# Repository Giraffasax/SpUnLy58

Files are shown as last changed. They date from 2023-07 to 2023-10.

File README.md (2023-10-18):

# The SpUnLy58 Keyboard
The SpUnLy58 is **Sp**layed **Un**ibody Li**ly58** layout [6*4 + 4key] keyboard. This is a minimal design keyboard that is wireless first. This design requires a Nice!Nano v2, supports a Nice!View,there are no LEDs, and a case is recommended to protect the up to 750mAh battery.

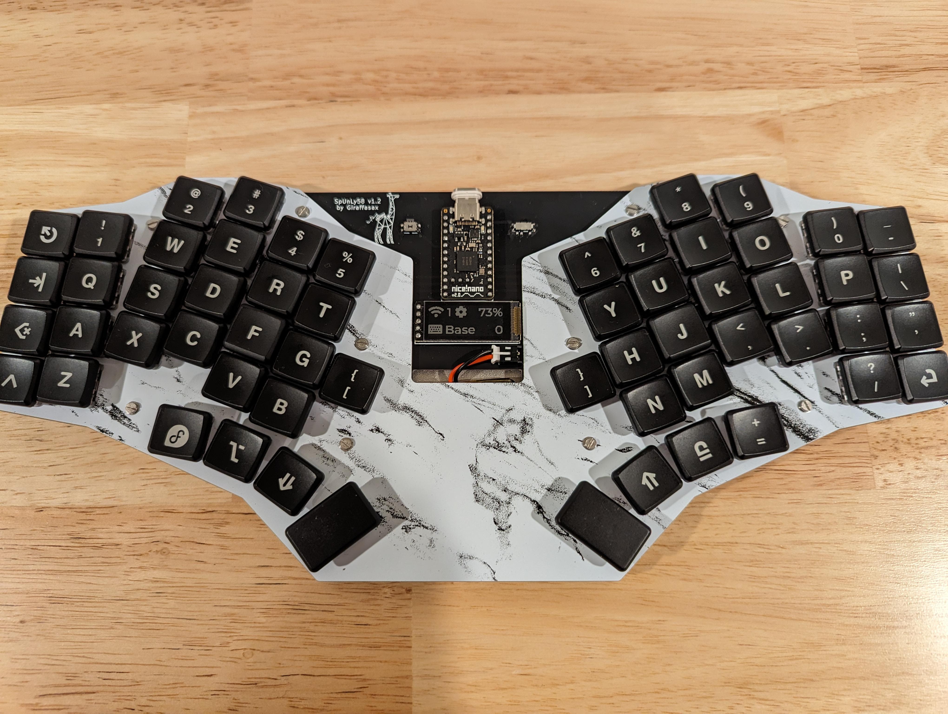
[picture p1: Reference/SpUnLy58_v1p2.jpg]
SpUnLy58_v1

<p style="text-align: center;">Build of SpUnLy v1.2 <p>

## Notable Features
- Choc V1 support [Hotswap and Soldered]
- "Split" unibody design with 19 deg angle (measured at middle finger column)
- Column Stagger
- Aggressive Pinky splay with Minimal splay for all other columns
- Aggressive Pinky stagger
- Fanned Thumb Cluster
- Nice!Nano v2 **[ REQUIRED ]**
- Nice!View Support
- JST Battery Connector

## SpUnLy58 v1.1 Updates
- Reduced vertical spacing from 18mm -> 17mm
- Increased battery cutout from 36x52mm -> 37x57mm
- Fixed incorrect JST connector footprint
## SpUnLy58 v1.2 Updates
- Removed inner and outer column splay
- Increased pinky stagger
- Reduced thumb key spacing and increased fan angle
- Added Ground fill

### Sponsor:
PCBway sponsored the manufacturing of v1.2 main pcb and the stainless steel bottom plates. If you would like to see more pictures and read my review see them [here.](Reference/PCBWay_Review.md)
___
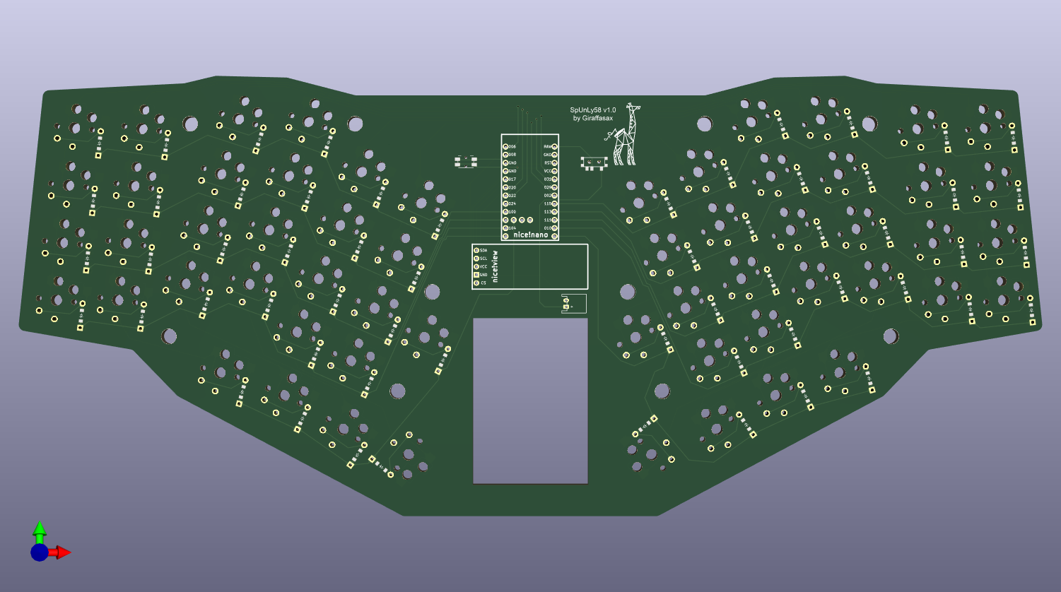
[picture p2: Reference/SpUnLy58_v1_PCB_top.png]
v1_PCB_top

<p style="text-align: center;">SpUnLy58 v1 PCB<p>

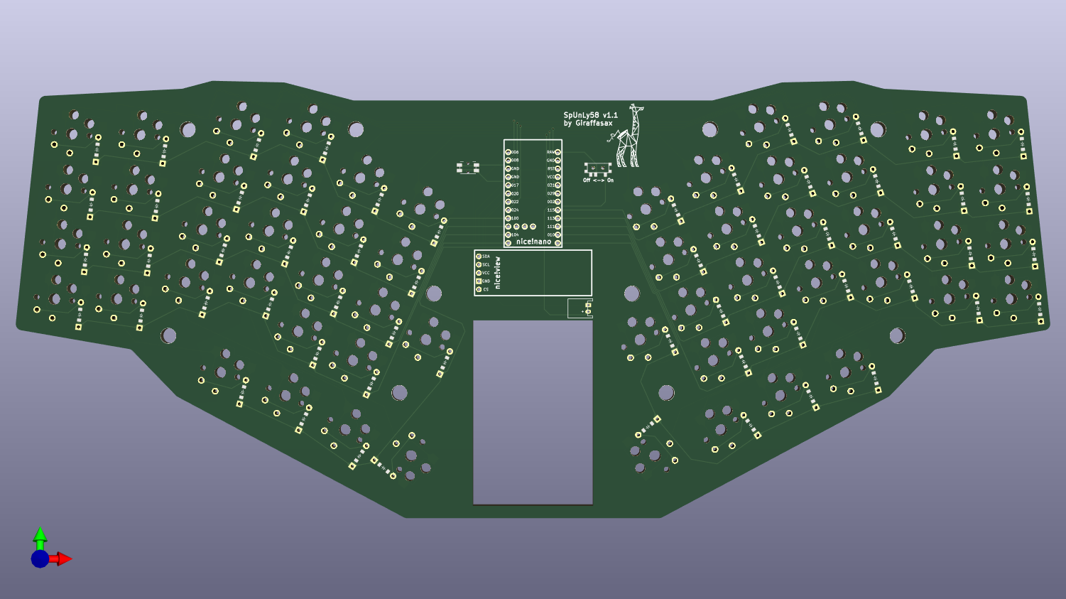
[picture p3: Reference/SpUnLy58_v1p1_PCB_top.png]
v1p1_PCB_top

<p style="text-align: center;">SpUnLy58 v1.1 PCB<p>

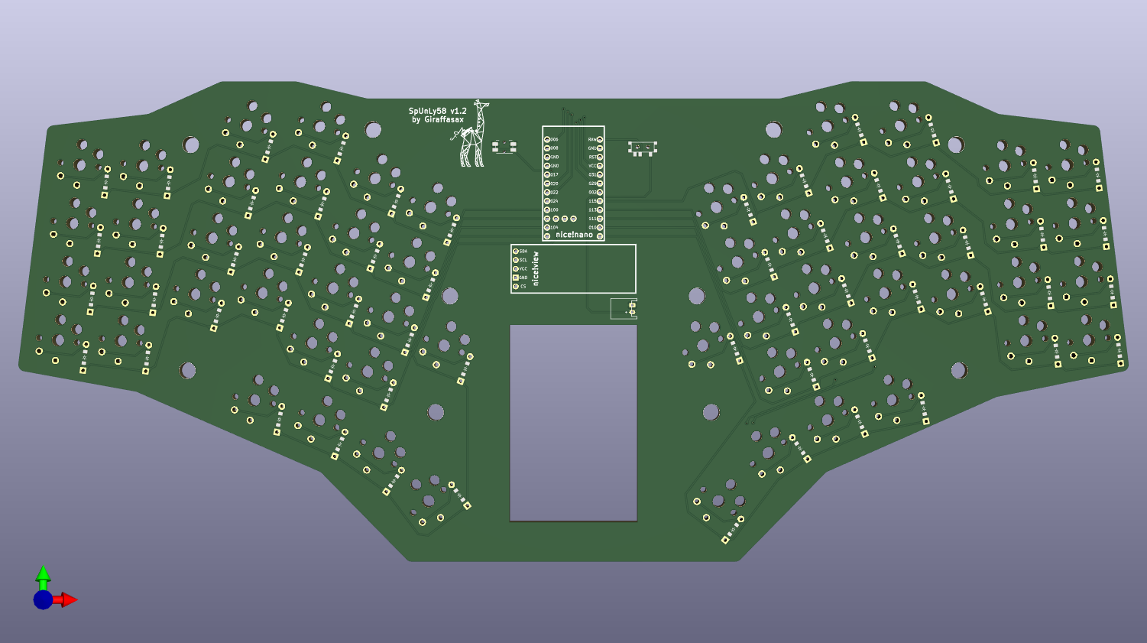
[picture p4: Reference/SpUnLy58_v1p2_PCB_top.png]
v1p2_PCB_top

<p style="text-align: center;">SpUnLy58 v1.2 PCB<p>

___
## Parts List 
| Name | Quantity | Example URL |
|---|---|---|
| SpUnLy58 PCB | 1  | https://github.com/Giraffasax/SpUnLy58/blob/main/KiCad/Gerber/SpUnLy58_Gerber.zip |
| Kailh Choc v1 Switches | 58 | https://typeractive.xyz/products/choc-switches?variant=46024772387047 |
| Kailh Choc v1 Keycaps (Choc Spacing) | 58 | https://fkcaps.com/custom/create/keycaps?option=mbk-pbt-pu&color=black |
| Nice!Nano v2 | 1 | https://typeractive.xyz/products/nice-nano |
| Nice!View or OLED (Optional) | 1 | https://typeractive.xyz/products/nice-view |
| Mill Max Ultra Low Profile Sockets (Optional) | 2 | https://www.littlekeyboards.com/collections/miscellaneous/products/ultra-low-profile-sockets |
| 1N4148W Diodes (SMD or TH) | 58 | https://typeractive.xyz/products/smd-diodes |
| Kailch Choc Hotswap Sockets (Optional) | 58 | https://typeractive.xyz/products/hotswap-sockets?variant=45742200324327 |
| Panasonic EVQPU Reset Switch | 1 | https://typeractive.xyz/products/reset-button |
| Alps miniature SPDT switch | 1 | https://typeractive.xyz/products/power-switch |
| JST PH 2.0mm Battery Jack | 1 | https://typeractive.xyz/products/battery-jack |
| 3.7v 750mAh 403450 Battery | 1 | https://typeractive.xyz/products/lithium-battery-750mah |

Note: I used the ultra low profile Mill Max sockets for both the controller and display to have them sit lower than the switch height to protect them in travel.

## Sandwich Case Part List
| Name | Quantity | Example URL |
|---|---|---|
| Bottom Plate - PCB | 0 or 1 | https://github.com/Giraffasax/SpUnLy58/blob/main/KiCad/Gerber/Bottom_Plate_Gerber.zip |
| Bottom Plate - Metal | 0 or 1 | https://github.com/Giraffasax/SpUnLy58/blob/main/KiCad/SpUnLy58_Bottom.step |
| Top Plate | 1 | https://github.com/Giraffasax/SpUnLy58/blob/main/KiCad/Gerber/Top_Plate_Gerber.zip |
| 6mm M2 Standoffs | 10 | https://splitkb.com/products/brass-m2-spacers?variant=42396969140483 |
| 4mm M2 Screws | 20 | https://splitkb.com/products/m2-screws?_pos=2&_sid=9c9502b8a&_ss=r |

## Firmware
ZMK Firmware: https://github.com/Giraffasax/zmk-SpUnLy58-config

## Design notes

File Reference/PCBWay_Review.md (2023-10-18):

# PCBWay Sponsored Review
## Background
After posting v1.0 of this project and it gaining some traction a PCBWay representative reached out to see if I would want them to sponsor my next iteration in exchange for a review. So I want to be up front that **I did receive a voucher for their services** which I used to help pay for the 5 main PCBs and 2 stainless steel bottom plates. I did not send this review to them beforehand. However, after posting the original review I was contacted and asked to remove the name of the competing China PCB manufacturer. To meet this request I have redacted the name and replaced it with "Unnamed PCB Supplier".

## Physical Comparison

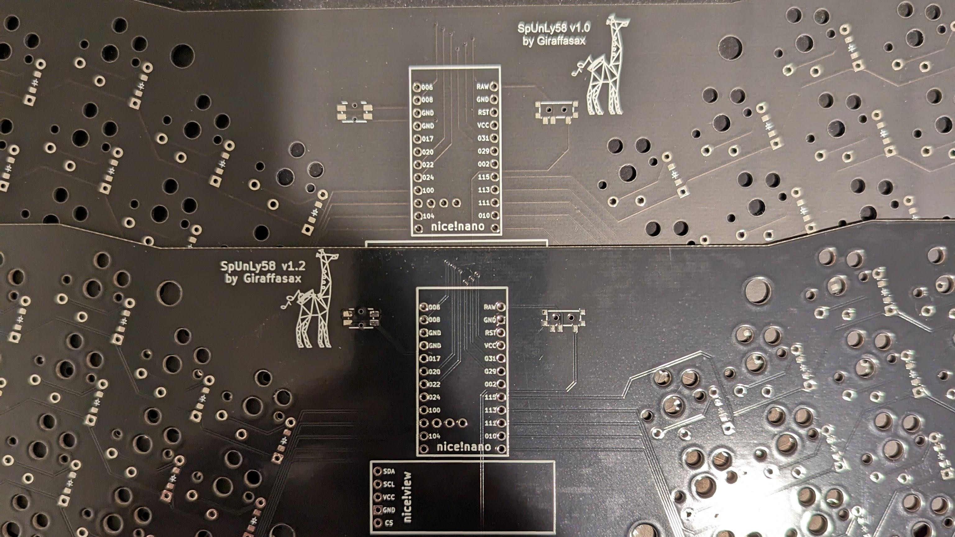
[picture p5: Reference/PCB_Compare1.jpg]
PCB Compare 1

<p style="text-align: center;">[top] "Unnamed PCB Supplier" Black [bottom] PCBWay Black</p>

First when comparing v1.0 that was printed by "Unnamed PCB Supplier" to v1.2 printed by PCBWay you can see that the "Unnamed PCB Supplier" "Black" PCB is a matte finish and a lighter tone while PCBWay's is a deeper black with a glossy finish. If you want a matte black from PCBWay there will be a slight up charge.

I was unable to directly compare the PCB weights as I added a ground fill on v1.2 that added quite a bit more material.

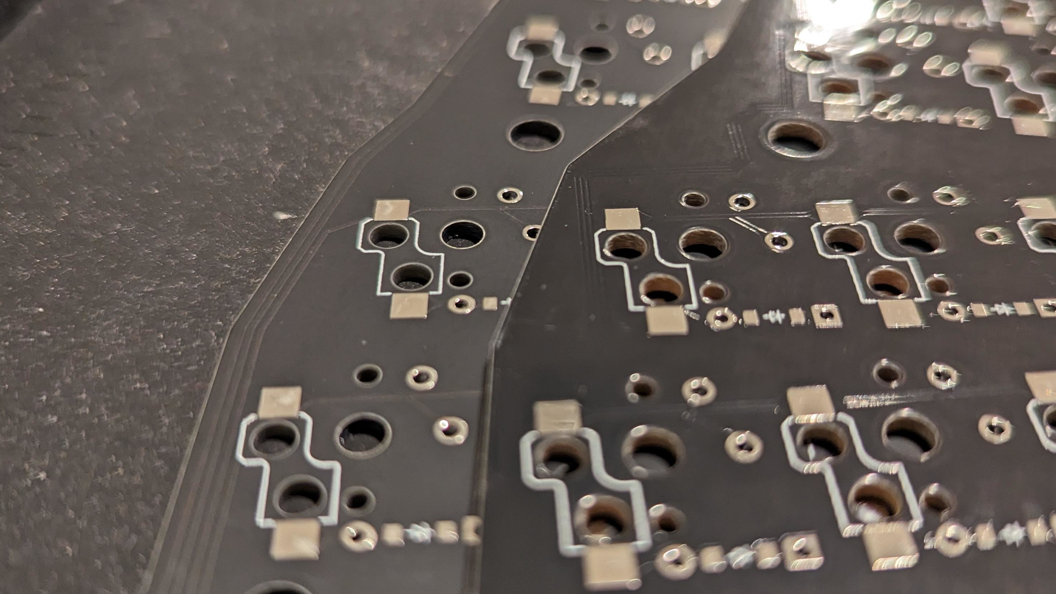
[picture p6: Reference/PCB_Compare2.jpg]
PCB Compare 1

<p style="text-align: center;">[left] "Unnamed PCB Supplier" Black [right] PCBWay Black</p>

Inspecting the pads and through holes on the PCBs I had a difficult time finding any differences on these very simple keyboard designs without any embedded controllers or other small components. The only difference I was able to see was a slight "wavy" appearance on the "Unnamed PCB Supplier" pads compared to the smoother appearance of the PCBWay. However I could not feel any variation in height of the "Unnamed PCB Supplier" pads and it did not affect my soldering whatsoever. So this is likely just cosmetic.

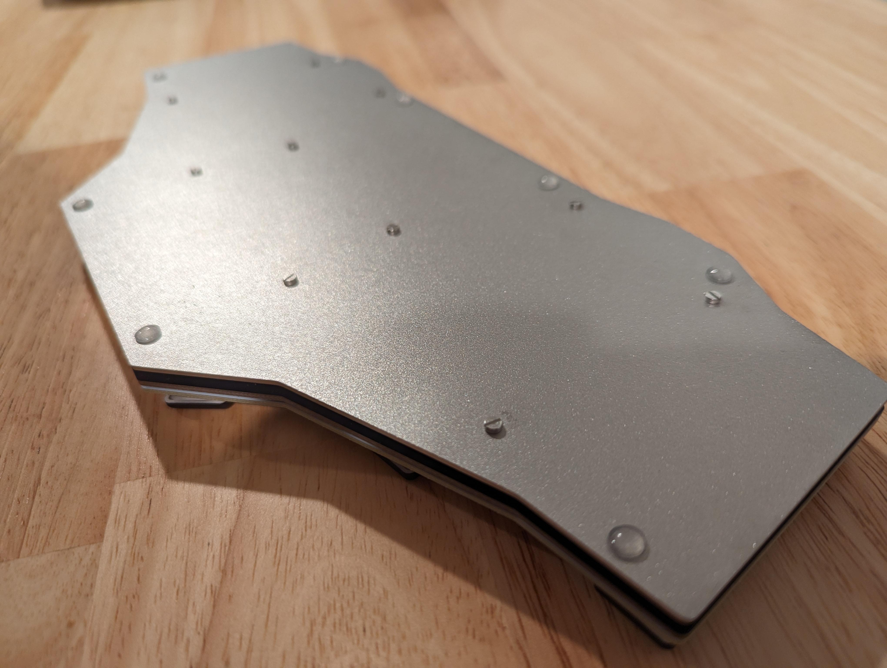
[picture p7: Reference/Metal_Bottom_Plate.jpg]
Metal_Bottom_Plate

<p style="text-align: center;">Stainless Steel Bottom Plate (PCBWay)</p>

I also put my PCBWay voucher towards getting a nice pair of stainless steel bottom plates for my work and home boards. I was able to upload a STEP file of the bottom plate to their "Sheet Metal" quote system. This service can be used for laser cutting and bending, but all I required was cutting. I selected a standard thickness of 1.5mm and chose a bead blasted finish which I think came out great.

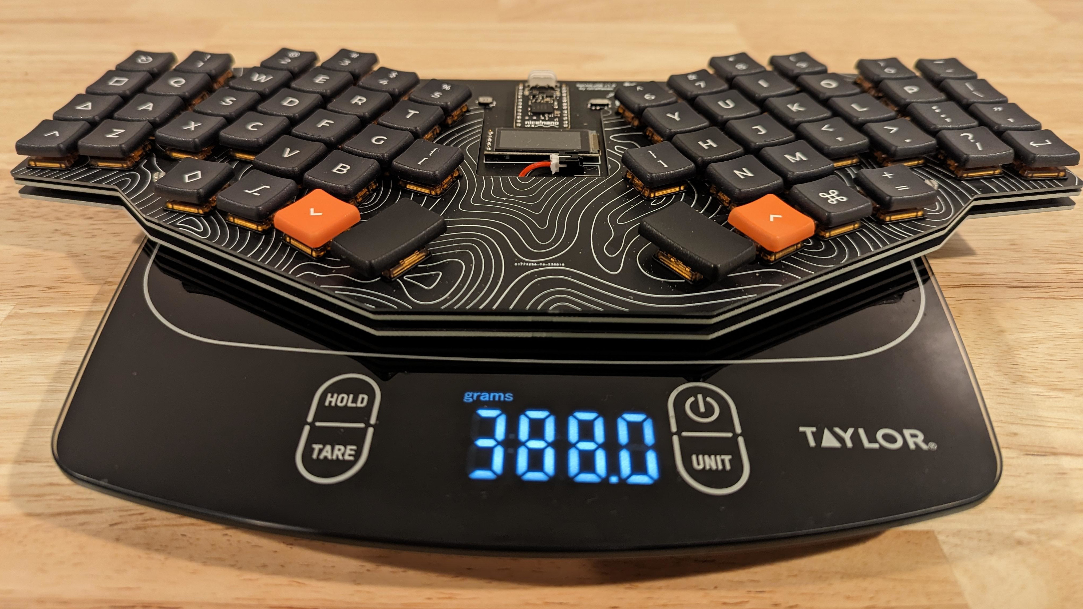
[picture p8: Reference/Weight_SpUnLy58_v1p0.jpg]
Weight_SpUnLy58_v1p0

<p style="text-align: center;">SpUnLy58 v1.0 assembled weight</p>

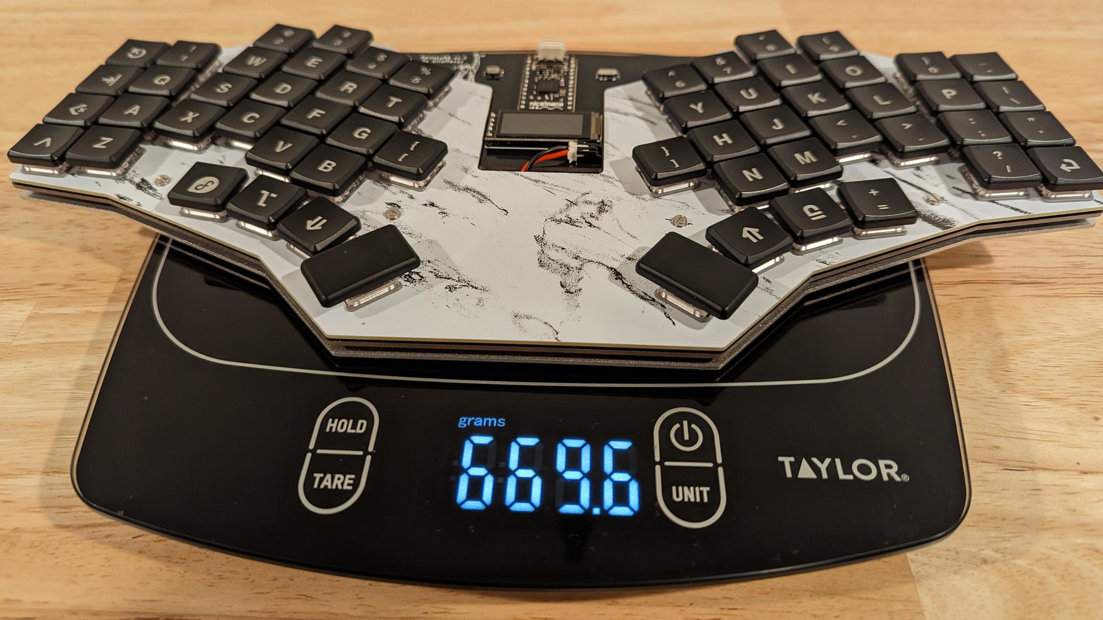
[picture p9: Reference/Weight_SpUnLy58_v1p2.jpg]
Weight_SpUnLy58_v1p2

<p style="text-align: center;">SpUnLy58 v1.2 assembled weight</p>

It also provides a pleasant heft. They have multiple options for each of the following materials: mild steel, stainless steel, aluminum, copper/brass, and acrylic. I think this service would also be a great option for switch plates or bent cases depending on your budget. "Unnamed PCB Supplier" and PCBWay also have 3d printing services that I have not tested.

## Purchase Experience
In both of my purchases with "Unnamed PCB Supplier" I submit my Gerber files, select my settings, and purchase. There seem to be some automated checks and they come back with pricing changes based on my PCBs. (ie. large number of cuts in the switch plate increasing the cost by $7.50)

When I did the same part submission process to PCBWay, I was asked some follow up questions by one of their engineers that helped me realize that I had accidentally uploaded the wrong gerber file. I was able to just email them the correct file, they updated my order, and I avoided a huge blunder. Now I cannot say whether or not they give this attention to all orders or just sponsored orders as this was my first purchase from them.

## Price Comparison (USD)
Now as this is a large unibody design with a number row [approx. 320x140mm] the prices are much higher compared to smaller DIY boards out there. Each value below is the cost of for a minimum order of 5 PCBs. Shipping was the cheapest available, typically DHL Express.

I chose the same settings for the PCBs. Black, 2-Layer, 1.6mm thick (1.2 for switch plate), HASL lead free.

| PCB Costs | Switch Plate | PCB | Bottom Plate | Shipping |
|---|---|---|---|---|
| "Unnamed PCB Supplier" v1.0 | $28.60 | $24.69 | $24.69 | $58.96 |
| "Unnamed PCB Supplier" v1.2 | $29.72 | N/A | $22.22 | $38.06 |
| PCBWay v1.2 | N/A | $94.80 | N/A | $30.56 |

Cost for two 1.5mm stainless steel bottom plates to be laser cut and bead blasted from PCBWay was **$80.12**

As you can see there was a reason why I didn't use PCBWay for all components of the build. Tinkering with the online quote system PCBWay can be 4-5x the cost of "Unnamed PCB Supplier" (before shipping). This isn't very noticeable on small boards where the difference is a few bucks. But when you scale it up to a board of my size the cost difference is sizable and it was cheaper to get 2 nice stainless steel bottom plates than have them cutout 5 plain FR4 plates.

## Conclusion
Overall PCBWay has slightly better cosmetic consistency with their pads, the customer service was great, and they have a lot of cool manufacturing options for metal and plastic materials. If you are looking to make a smaller board I recommend them, however for a large board like mine I cannot justify the price discrepancy without a sponsored voucher.

If you would like a more in depth review of PCBWay and other suppliers and their capabilities on a more complex PCB design, I recommend [Icamtuf's substack post.](https://lcamtuf.substack.com/p/comparing-hobby-pcb-vendors)

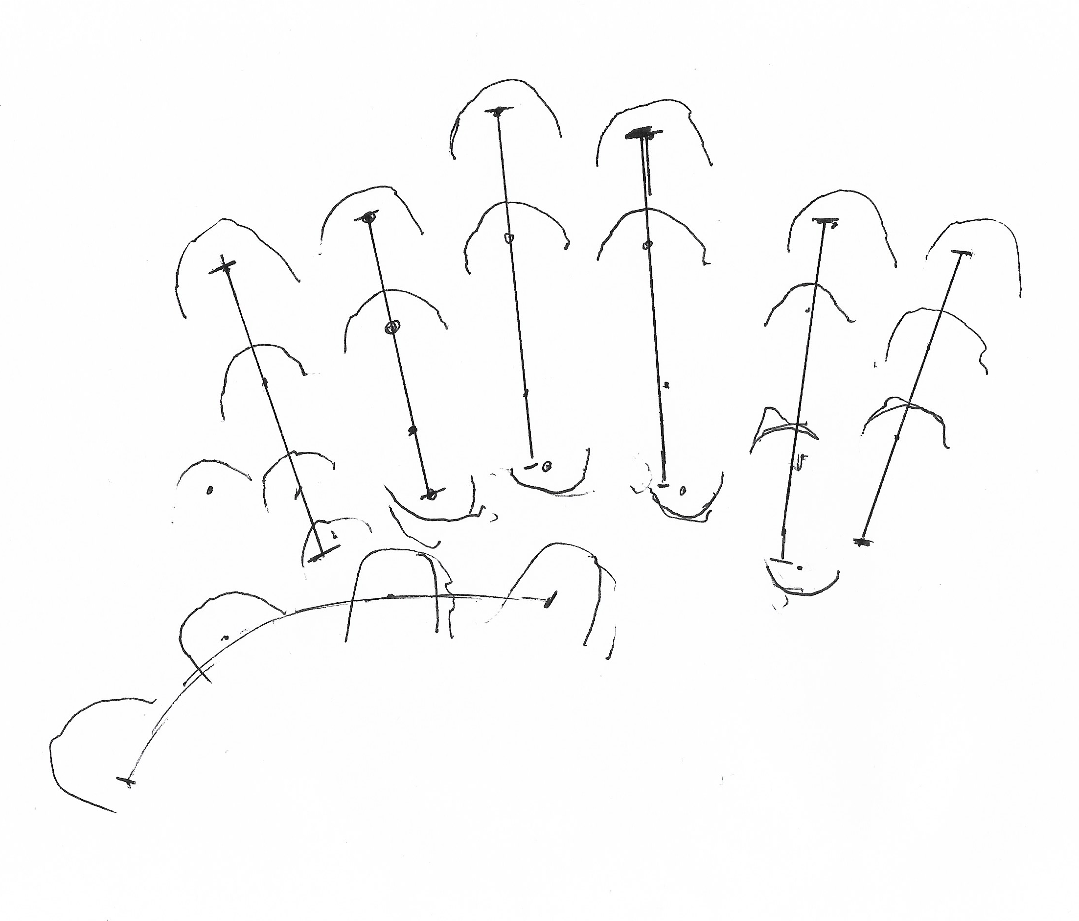
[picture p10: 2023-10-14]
Reference/Hand_Layout_Paper.png

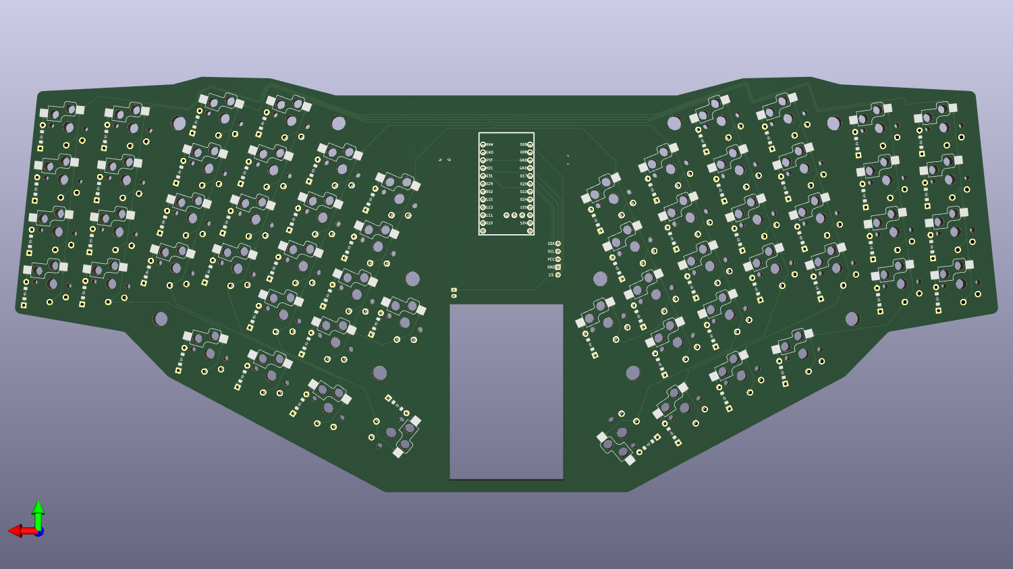
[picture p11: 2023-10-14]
Reference/SpUnLy58_v1p1_PCB_bottom.png

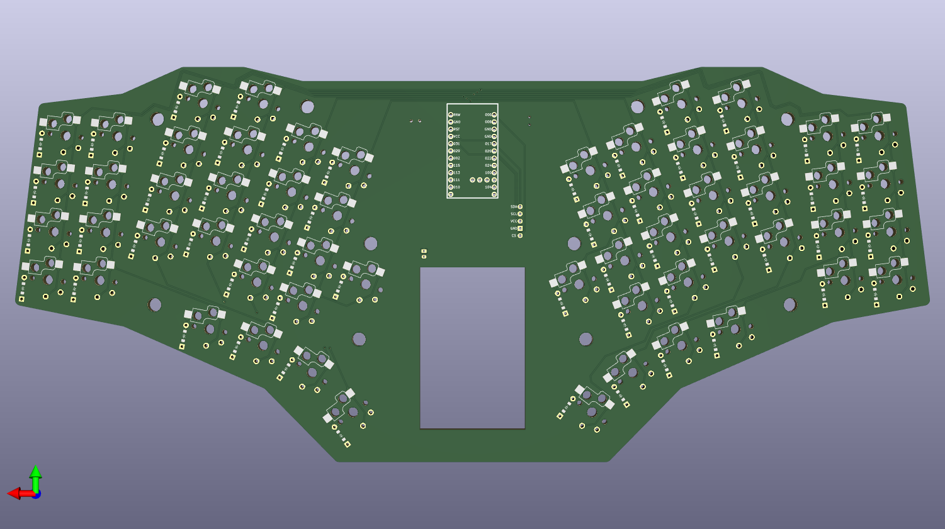
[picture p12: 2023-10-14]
Reference/SpUnLy58_v1p2_PCB_bottom.png

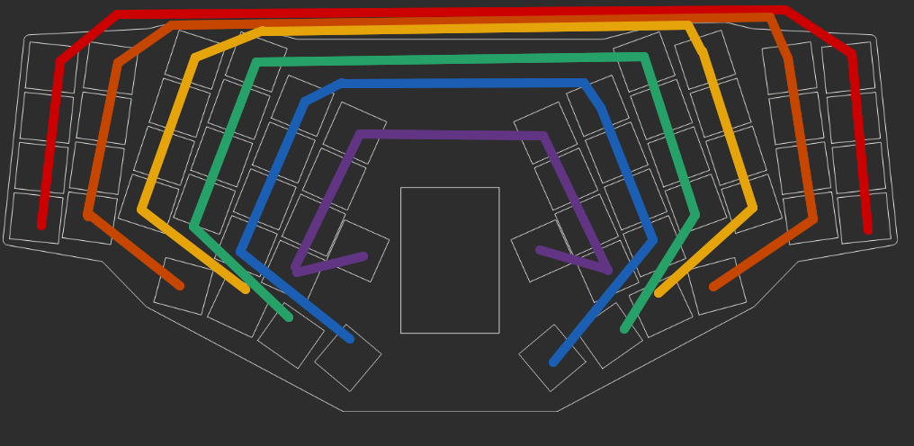
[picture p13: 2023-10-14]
Reference/Columns.png

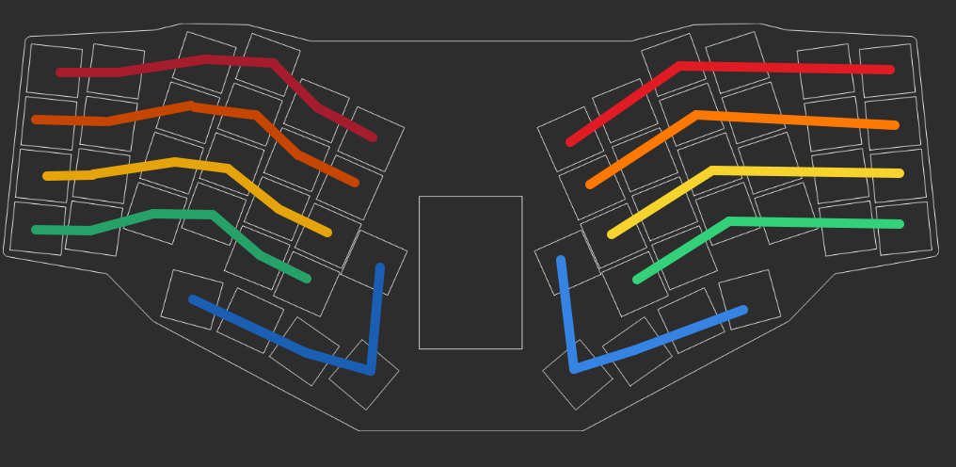
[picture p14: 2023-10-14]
Reference/Rows.png

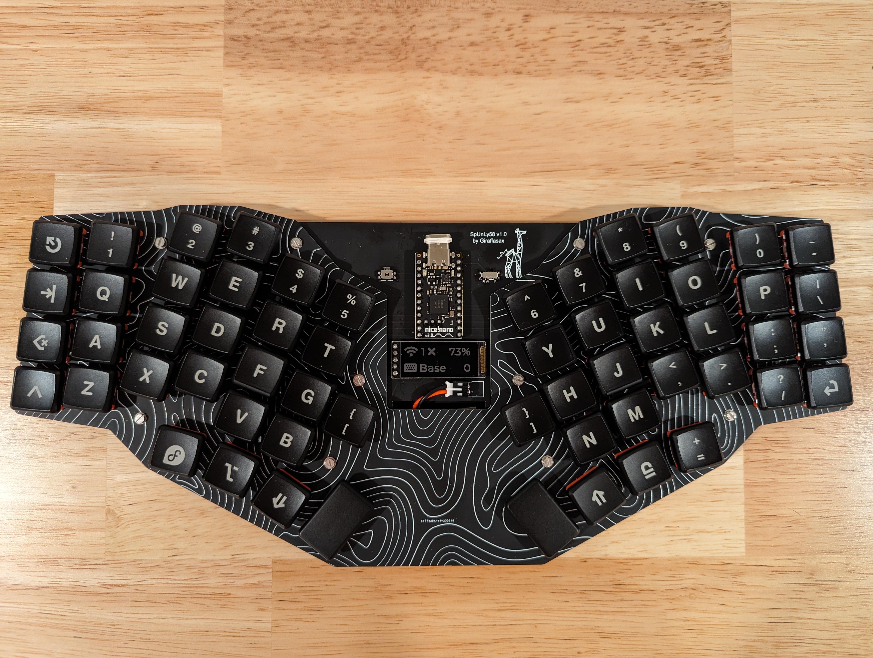
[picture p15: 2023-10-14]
Reference/SpUnLy58_v1.jpg

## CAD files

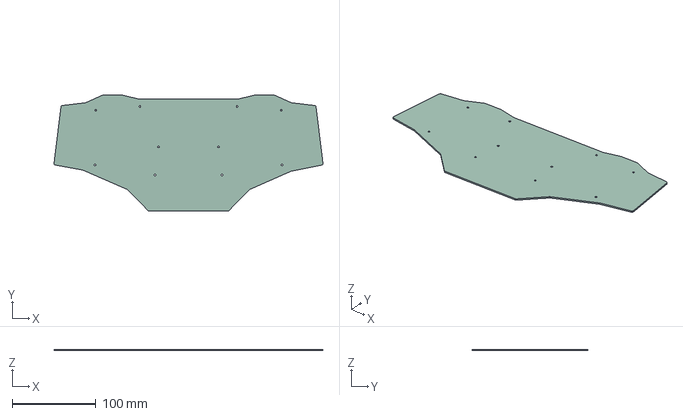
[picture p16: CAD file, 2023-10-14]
KiCad/SpUnLy58_Bottom.step
320.8 x 138.7 x 1.60 mm

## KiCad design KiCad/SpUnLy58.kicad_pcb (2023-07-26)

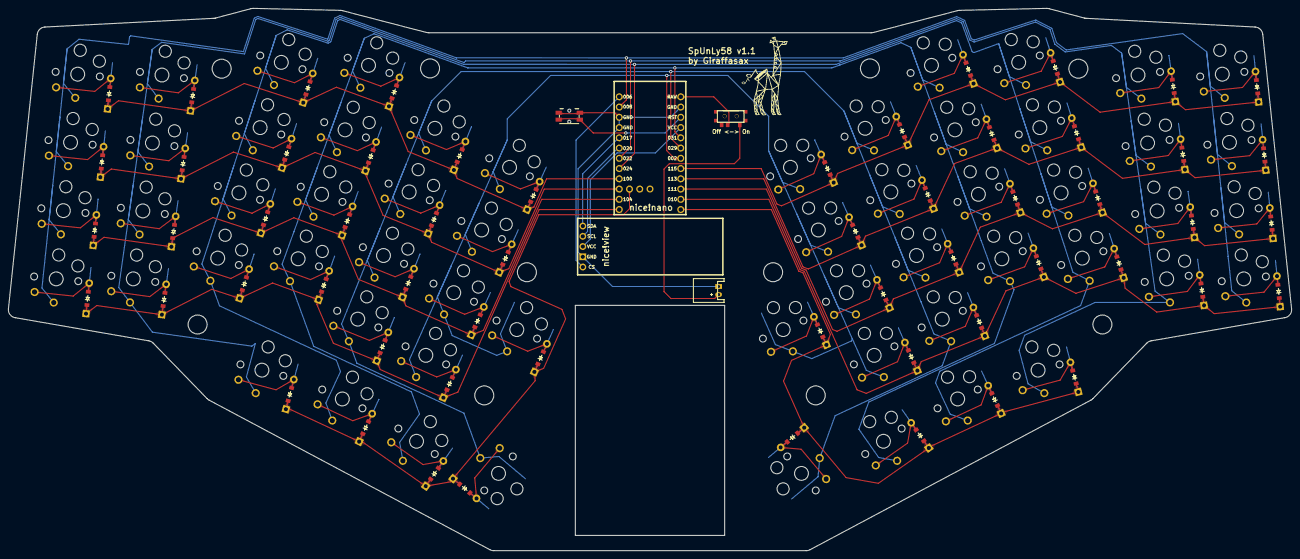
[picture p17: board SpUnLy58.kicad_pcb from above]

Board: 2 copper layers, 318.0 x 134.4 mm, 131 parts (0 on the bottom side), 82 nets.

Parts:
B1: Panasonic_EVQPUL_EVQPUC
D1, D2, D3, D4, D5, D6, D7, D8, D9, D10, D11, D12, D13, D14, D15, D16, D17, D18, D19, D20, D21, D22, D23, D24, D25, D26, D27, D28, D29, D30, D31, D32, D33, D34, D35, D36, D37, D38, D39, D40, D41, D42, D43, D44, D45, D46, D47, D48, D49, D50, D51, D52, D53, D54, D55, D56, D57, D58: ComboDiode
JST1: JST_PH_S2B-PH-K_02x2.00mm_Angled
MCU1: nice_nano
S1, S2, S3, S4, S5, S6, S7, S8, S9, S10, S11, S12, S13, S14, S15, S16, S17, S18, S19, S20, S21, S22, S23, S24, S25, S26, S27, S28, S29, S30, S31, S32, S33, S34, S35, S36, S37, S38, S39, S40, S41, S42, S43, S44, S45, S46, S47, S48, S49, S50, S51, S52, S53, S54, S55, S56, S57, S58: Kailh_socket_PG1350_optional_mkultra
T1: SPDT_C128955
_1, _2, _3, _4, _5, _6, _7, _8, _9, _10: HOLE_M2_TH
niceView1: niceView; niceView_headers

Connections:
GND: B1.1, JST1.1, MCU1.3, MCU1.4, MCU1.23, niceView1.2
P002: MCU1.18, S21.1, S22.1, S23.1, S24.1, S25.1, S50.1, S51.1, S52.1, S53.1, S54.1
P006: MCU1.1, niceView1.1
P008: MCU1.2, S1.1, S2.1, S3.1, S4.1, S30.1, S31.1, S32.1, S33.1
P009: D54.1, D55.1, D56.1, D57.1, D58.1, MCU1.13
P010: D30.1, D34.1, D38.1, D42.1, D46.1, D50.1, MCU1.14
P011: D3.1, D7.1, D11.1, D15.1, D19.1, D23.1, MCU1.10
P017: MCU1.5, niceView1.5
P020: MCU1.6, niceView1.4
P022: MCU1.7, S5.1, S6.1, S7.1, S8.1, S26.1, S34.1, S35.1, S36.1, S37.1, S55.1
P024: MCU1.8, S9.1, S10.1, S11.1, S12.1, S27.1, S38.1, S39.1, S40.1, S41.1, S56.1
P029: MCU1.19, S17.1, S18.1, S19.1, S20.1, S29.1, S46.1, S47.1, S48.1, S49.1, S58.1
P031: MCU1.20, S13.1, S14.1, S15.1, S16.1, S28.1, S42.1, S43.1, S44.1, S45.1, S57.1
P100: D4.1, D8.1, D12.1, D16.1, D20.1, D24.1, MCU1.9
P101: D25.1, D26.1, D27.1, D28.1, D29.1, MCU1.31
P104: D2.1, D6.1, D10.1, D14.1, D18.1, D22.1, MCU1.11
P106: D1.1, D5.1, D9.1, D13.1, D17.1, D21.1, MCU1.12
P111: D31.1, D35.1, D39.1, D43.1, D47.1, D51.1, MCU1.15
P113: D32.1, D36.1, D40.1, D44.1, D48.1, D52.1, MCU1.16
P115: D33.1, D37.1, D41.1, D45.1, D49.1, D53.1, MCU1.17
RAW: MCU1.24, T1.2
RST: B1.2, MCU1.22
VCC: MCU1.21, niceView1.3
center_home: D25.2, S25.2
index_bottom: D17.2, S17.2
index_home: D18.2, S18.2
index_num: D20.2, S20.2
index_top: D19.2, S19.2
inner_bottom: D21.2, S21.2
inner_home: D22.2, S22.2
inner_num: D24.2, S24.2
inner_top: D23.2, S23.2
layer_thumb: D28.2, S28.2
main_thumb: D29.2, S29.2
middle_bottom: D13.2, S13.2
middle_home: D14.2, S14.2
middle_num: D16.2, S16.2
middle_thumb: D27.2, S27.2
middle_top: D15.2, S15.2
mirror_center_home: D54.2, S54.2
mirror_index_bottom: D46.2, S46.2
mirror_index_home: D47.2, S47.2
mirror_index_num: D49.2, S49.2
mirror_index_top: D48.2, S48.2
mirror_inner_bottom: D50.2, S50.2
mirror_inner_home: D51.2, S51.2
mirror_inner_num: D53.2, S53.2
mirror_inner_top: D52.2, S52.2
mirror_layer_thumb: D57.2, S57.2
mirror_main_thumb: D58.2, S58.2
mirror_middle_bottom: D42.2, S42.2
mirror_middle_home: D43.2, S43.2
mirror_middle_num: D45.2, S45.2
mirror_middle_thumb: D56.2, S56.2
mirror_middle_top: D44.2, S44.2
mirror_outerp_bottom: D30.2, S30.2
mirror_outerp_home: D31.2, S31.2
mirror_outerp_num: D33.2, S33.2
mirror_outerp_top: D32.2, S32.2
mirror_outerth_thumb: D55.2, S55.2
mirror_pinky_bottom: D34.2, S34.2
mirror_pinky_home: D35.2, S35.2
mirror_pinky_num: D37.2, S37.2
mirror_pinky_top: D36.2, S36.2
mirror_ring_bottom: D38.2, S38.2
mirror_ring_home: D39.2, S39.2
mirror_ring_num: D41.2, S41.2
mirror_ring_top: D40.2, S40.2
outerp_bottom: D1.2, S1.2
outerp_home: D2.2, S2.2
outerp_num: D4.2, S4.2
outerp_top: D3.2, S3.2
outerth_thumb: D26.2, S26.2
pinky_bottom: D5.2, S5.2
pinky_home: D6.2, S6.2
pinky_num: D8.2, S8.2
pinky_top: D7.2, S7.2
pos: JST1.2, T1.1
ring_bottom: D9.2, S9.2
ring_home: D10.2, S10.2
ring_num: D12.2, S12.2
ring_top: D11.2, S11.2

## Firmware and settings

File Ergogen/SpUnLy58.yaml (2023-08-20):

units:
  thb_sp: 19.75
  px: cx+3
  py: cy+3
points:
  key:
    spread: cx
    padding: cy
    width: cx-0.5
    height: cy-0.5
  zones:
    matrix:
      # Fix placement on KiCAD sheet.
      anchor:
        shift: [75, -125]
      columns:
        outerp:
          key.column_net: P008
        pinky:
          key:
            stagger: 2
            spread: cx
            column_net: P022
        ring:
          key:
            stagger: 16
            spread: cx+1.5
            splay: -10
            column_net: P024
        middle:
          key:
            stagger: 6
            splay: -2
            spread: cx+0.5
            column_net: P031
        index:
          key:
            stagger: -9
            spread: cx+0.25
            splay: -2
            column_net: P029
        inner:
          key:
            stagger: -2
            spread: cx
            column_net: P002
        center:
          key:
            skip: true
            stagger: -2
            column_net: P002
          rows:
            home.skip: false
            home.row_net: P101
            home.mirror.row_net: P009
      rows:
        bottom:
          row_net: P106
          mirror.row_net: P010
        home:
          row_net: P104
          mirror.row_net: P111
        top:
          row_net: P011
          mirror.row_net: P113
        num:
          row_net: P100
          mirror.row_net: P115
    thumbfan:
        anchor:
          ref: matrix_middle_bottom
          shift: [8,-30]
        columns:
          outerth:
            key:
              splay: 8
              column_net: P022
          middle:
            key:
              spread: thb_sp
              splay: -12
              stagger: 0
              origin: [-10]
              column_net: P024
          layer:
            key:
              spread: thb_sp
              splay: -12
              origin: [-10]
              column_net: P031
          main:
            key:
              width: 1.5cx
              rotate: 90
              stagger: 0
              spread: thb_sp+0.5
              splay: -18
              origin: [-10]
              column_net: P029
        rows:
          thumb:
            row_net: P101
            mirror.row_net: P009
  rotate: -7
  mirror:
    ref: matrix_center_home
    distance: 75
outlines:
  keys:
    - what: rectangle
      where: true
      size: [cx-0.5,cy-0.5]
  switches:
    - what: rectangle
      where: true
      size: [14, 14]
  battery:
    - what: rectangle
      size: [37,57]
      where:
        ref.aggregate.parts: [matrix_center_home, mirror_matrix_center_home]
        shift: [0,-22.5]
  board:
    - what: polygon
      operation: stack
      points:
        - ref: thumbfan_main_thumb
          shift: [-0.75py,-0.5px]
        - ref: thumbfan_layer_thumb
          shift: [-0.5px,-0.7py]
        - ref: matrix_pinky_bottom
          shift: [0.3px,-0.7py]
        - ref: matrix_outerp_bottom
          shift: [-0.5px,-0.5py]
        - ref: matrix_outerp_num
          shift: [-0.5px,0.5py]
        - ref: matrix_pinky_num
          shift: [0,0.75py]
        - ref: matrix_ring_num
          shift: [-0.5px,0.5py]
        - ref: matrix_middle_num
          shift: [-0.5px,0.5py]
        - ref: matrix_middle_num
          shift: [0.5px,0.6py]
        - ref: mirror_matrix_middle_num
          shift: [0.5px,0.6py]
        - ref: mirror_matrix_middle_num
          shift: [-0.5px,0.5py]
        - ref: mirror_matrix_ring_num
          shift: [-0.5px,0.5py]
        - ref: mirror_matrix_pinky_num
          shift: [0,0.75py]
        - ref: mirror_matrix_outerp_num
          shift: [-0.5px,0.5py]
        - ref: mirror_matrix_outerp_bottom
          shift: [-0.5px,-0.5py]
        - ref: mirror_matrix_pinky_bottom
          shift: [0.5px,-0.75py]
        - ref: mirror_thumbfan_layer_thumb
          shift: [-0.5px,-0.7py]
        - ref: mirror_thumbfan_main_thumb
          shift: [-0.75py,-0.5px]
      fillet: 2
  plate_out:
    - what: polygon
      operation: stack
      points:
        - ref: thumbfan_main_thumb
          shift: [-0.75py,-0.5px]
        - ref: thumbfan_layer_thumb
          shift: [-0.5px,-0.7py]
        - ref: matrix_pinky_bottom
          shift: [0.3px,-0.7py]
        - ref: matrix_outerp_bottom
          shift: [-0.5px,-0.5py]
        - ref: matrix_outerp_num
          shift: [-0.5px,0.5py]
        - ref: matrix_pinky_num
          shift: [0,0.75py]
        - ref: matrix_ring_num
          shift: [-0.5px,0.5py]
        - ref: matrix_middle_num
          shift: [-0.5px,0.5py]
        - ref: matrix_middle_num
          shift: [0.5px,0.6py]
        - ref: matrix_index_num
          shift: [0.6px,0.6py]
        - ref: matrix_inner_num
          orient: 21
          shift: [22.5,5]
        - ref: matrix_inner_num
          orient: 21
          shift: [22.5,-39]
        - ref: mirror_matrix_inner_num
          orient: 21
          shift: [22.5,-39]
        - ref: mirror_matrix_inner_num
          orient: 21
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

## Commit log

2023-06-09 Added plate and bottom case pcbs Finished mounting hole positions Added new choc js file with hot swap and through hole Moved diodes
    [SpUnLy58.yaml]
2023-06-12 Initial KiCad PCB files for keyboard and case
    [SpUnLy58.kicad_pcb, SpUnLy58_Bottom.kicad_pcb, SpUnLy58_Plate.kicad_pcb]
2023-06-12 fixed error in column net pointing to wrong pin.
    [SpUnLy58.yaml]
2023-06-14 tuned tracks, moved mounting hole.
    [SpUnLy58.kicad_pcb, SpUnLy58_Bottom.kicad_pcb, SpUnLy58_Plate.kicad_pcb]
2023-06-17 Version 1.0 complete. Finalized routes. Added graphics.
    [SpUnLy58.kicad_pcb, SpUnLy58_Bottom.kicad_pcb, SpUnLy58_Plate.kicad_pcb]
2023-06-18 Modified plate cutout from 13.8 to 14mm
    [SpUnLy58_Plate.kicad_pcb]
2023-07-26 [v1.1] Reduced vertical spacing from 18 to 17mm Fixed jstph connector footprint and pad label. Increased cutout for battery.
    [SpUnLy58.kicad_pcb, SpUnLy58_Bottom.kicad_pcb, SpUnLy58_Plate.kicad_pcb]
2023-08-12 Remove stagger for outer pinky and inner columns. Tightened lateral spacing overall. Higher overall rotation of thumbkey Increased distance between halves Decrease hand angle from 20 to 17 deg
    [SpUnLy58.yaml]
2023-08-20 Final v1p2 layout. Update yaml, kicad pcb, and gerber
    [SpUnLy58_Bottom.kicad_pcb, SpUnLy58_Plate.kicad_pcb]
2023-10-14 Final Tuning and update to README
    [SpUnLy58_Bottom.kicad_pcb, SpUnLy58_Bottom.step]
2023-10-18 Fixed ReadME typo. Added PCBWay review. Modified pic aspect ratios.
